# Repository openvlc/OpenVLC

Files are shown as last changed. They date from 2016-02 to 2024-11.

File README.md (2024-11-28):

# OpenVLC 

This is the repository for the OpenVLC platform, an open-source, flexible and low-cost Visible Light Communication System platform. The research and development is led by IMDEA Networks Institute, Spain, but anyone is welcome to contribute.

## New OpenVLC1.3 version

<p align="center">
  
</p>

We are delighted to announce that OpenVLC1.3 is ready for delivery! OpenVLC1.3 can now achieve a throughput of 400 Kb/s at the Transport Layer at a distance of more than 3 meter, powered simply by the BeagleBone Black!

<!--- Details on how to get started are available at http://www.openvlc.org/instructions.html --->
Details on how to get started are introduced below.

## Instructions

OpenVLC needs just a few components to work:

1. **BEAGLEBONE Black (BBB) Board** _**(needs Rev C produced from 2017; you need to connect an external 5V power supply to the BBB):**_ cost $ 45 - $ 60; AM3359 1 GHz, 4 timers, 65 GPIOs
2. **OpenVLC1.3 RevA cape:**  the VLC front-end
3. **OpenVLC1.3 driver:** software defined MAC and PHY layer (implemented as Linux driver) and firmware (to control the programmable real time units of the BBB (PRU))

The software solution is implemented as a Linux driver that can communicate directly with the cape and the Linux networking stack. In OpenVLC, the VLC interface is set up as a new communication interface that can take advantage of the vast range of Linux tools.

### Design of OpenVLC

The new OpenVLC1.3 takes advantage of the programmable real time units (PRU) included in the BBB. This,and the new receiver design allow us to increase the transmission frequency to 1 MHz and, thus, the communication rate. One cape can work as Transmitter (TX) or Receiver (RX).

<p align="center">
  
</p>

### Testing the cape
Although OpenVLC 1.3 cape is designed to be connected to the BBB, its functionalities can be tried without one. This step is not essential and requires additional devices such as a waveform generator or an oscilloscope. But it can be useful to test its correct functioning before plugging it to the BBB and to avoid possible damages to the board.

#### TX mode
Set the connections shown in image below. Connect a 5 V power supply to the jack port. To emulate a transmission with OpenVLC 1.3 you can produce in the cape pin TX SIGNAL (P8_45 in BBB) a square wave between 0 and 3.3 V at 1 MHz. The LED should light on without any noticeable blinking. Modulated light can be measured with a fast light-sensing device (photodiode) connected to an oscilloscope.
To test constant illumination, connect TX SIGNAL to GND and the pin next to it (P8_46) to 3.3 V. The LED should provide similar illumination level than in the previous case.

<p align="center">
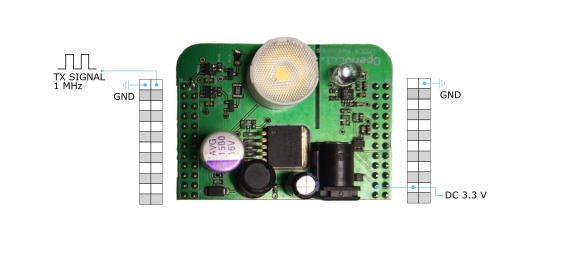
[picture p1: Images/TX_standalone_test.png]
  
</p>

#### RX mode
Set the connections shown in image below. Connect a 5 V power supply to the jack port. Produce a square wave between 0 and 3.3 V at 1 MHz at ADC CS, and a square wave between 0 and 3.3 V at 48 MHz at ADC SCLK. You can read the serial digital output from the ADC in the cape on pin RX SIGNAL.

<p align="center">
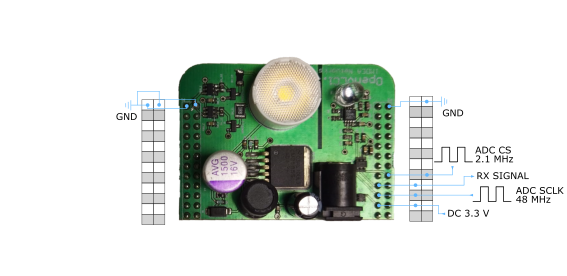
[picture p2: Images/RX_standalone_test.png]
  
</p>

### Experimental Setup

#### Creating the SD Card

We need to flash the BBB with a Debian image. To do that we need a SD Card with at least 4 GB. Follow these steps:

* Format the SD Card with SD card formatter with overwrite format.
* Download the image from the link:https://files.beagle.cc/file/beagleboard-public-2021/images/bone-debian-8.7-iot-armhf-2017-03-19-4gb.img.xz
* Write the image _”bone-debian-8.7-iot-armhf-2017-03-19-4gb”_ to the SD Card. If you use Windows, you may use Win32 Disk Imager. For Linux, you may use the command line dd.

#### Flashing the BBB

Now that we have the SD Card ready with the image, we need to flash the BBB. Follow these steps:

* With the power disconnected, insert the SD Card into the BBB and power it up with the USB cable.
* Connect through SSH to the IP 192.168.7.2.
* In order to run the OS on the SD Card, flash it into the BBB: go to _/opt/scripts/tools/eMMC_ and run _sudo ./bbb-eMMC-flasher-eewiki-ext4.sh_ 
* Wait until the script of previous steps reports the following message: “eMMC has been flashed”. Once it finishes, disconnect the usb cable and with the BBB switched off, remove the SD Card.

#### Setting up the OS

The firsts steps are to prepare the beaglebone. This must be done in the OpenVLC board operating as TX as well as in the OpenVLC board operating as RX. These are the steps:

* Disable the HDMI: The HDMI uses some PRU pins that we need. To disable the HDMI cape edit the uEnv.txt file: _sudo nano /boot/uEnv.txt_ and uncomment the line: _dtb=am335x-boneblack-emmc-overlay.dtb_
* Reboot the OpenVLC board. The HDMI is disable after rebooting.
* Install the headers: Connect the beaglebone to the Internet, and then update with: _sudo apt-get update_
* Then the board is ready to install the headers with: _sudo apt-get install linux-headers-$(uname -r)_
The code is in github at https://github.com/openvlc/OpenVLC. In Latest_Version subdirectory you will find the Driver (kernel) and PRU code folders. Just fetch them by using _sudo git clone https://<span></span>github.com/openvlc/OpenVLC_, and copy them into the path ”/home/Debian”.

#### Connecting the cape

Connecting the cape to the BBB is quite easy. You just need to plug the cape to the correct pins as shown in the image below:

<p align="center">
  
</p>

Once it’s plugged, connect the 5 V power supply and that’s all.

**ATTENTION:** Be careful not to bend the components that stand out when you press or pull the cape.

#### Setting up the TX/RX

There are two parts in the TX/RX, the kernel driver and the PRU code. Follow these steps: 

* In order to load the kernel driver, run the following command inside the Driver folder: _sudo ./load_test.sh._ With this script, you can change the IP taken by the interface. That’s the IP in the VLC network, so TX and RX must have different IPs (for example TX: 192.168.0.1 and RX 192.168.0.2).
* Once the module driver is installed, make sure that proper paths and symbolic links have been made for the PRU compiler (clpru) and linker (lnkpru). The following commands can be used to this end:

    _cd /usr/share/ti/cgt-pru_<br/>
    _sudo mkdir bin_<br/>
    _cd bin_<br/>
    _sudo ln -s /usr/bin/clpru clpru_<br/>
    _sudo ln -s /usr/bin/lnkpru lnkpru_<br/>

* Then go to the PRU folder, enter TX/RX and run sudo _./deploy.sh_. This will boot up the PRUs with the code necessary to transmit and receive VLC data.
    
#### Working with the TX/RX

Once you have done the steps above in TX and RX, you can start using VLC as a common network interface.

You could measure the achievable throughput by using the iperf tool. To this end, launch iperf in client mode at the TX (_sudo iperf -c 192.168.0.2 -u -b 400k -l 800 -p 10001 -t 100_) and in server mode at the RX (_sudo iperf -u -l 800 -s -i3 -B 192.168.0.2 -p 10001_). Make sure that TX and RX have different IPs and the IP of the RX (iperf server) is 192.168.0.2.

The image below shows the results of an iperf test at 2.5 meters of distance:

<p align="center">
  
</p>

### Feedback

If you have doubts and questions about these instructions, please leave your message in our Google group: https://groups.google.com/forum/#!forum/openvlc

## What is Visible Light Communication - LiFi? 

Visible Light Communication (VLC), sometimes also referred to as “LiFi", uses standard off-the-shelf visible light LEDs to transmit data using the visible light spectrum. VLC is receiving strong attention from the designers of the 5G networks and beyond. VLC can enable new pervasive wireless systems in the context of the Internet of Things.

## Our Mission 

The lack of an open-source and low-cost reference platform is hindering the progresses of research and industry in VLC systems. A general-purpose platform would add momentum to VLC and would open up new avenues of VLC research and spark the interest of researchers and engineers.  We take an initial step toward this and we design OpenVLC, an open-source Visible Light Communication platform for fast prototyping of new system protocols to build a LiFi network. It runs on a cost-effective yet powerful credit-card-sized embedded board.

## Questions

If you have any questions, you can contact us at openvlc.networks@imdea.org and post your questions at https://groups.google.com/forum/#!forum/openvlc

## Citation

If you use openVLC for your research, please cite "B. Genoves, M. Mir, D. Frometa, A. Galisteo, Q. Wang, D. Giustiniano, "Prototyping Visible Light Communication for the Internet of Things Using OpenVLC ", IEEE Communications Magazine, 2023". 

## License

Driver code of OpenVLC is released under GNU General Public License v3.0 - see the [LICENSE_driver.md](Latest_Version/LICENSE_driver.md) file for details. PRU code of OpenVLC is released under  BSD-2 license - see the [LICENSE_pru.md](Latest_Version/LICENSE_pru.md) file for details.

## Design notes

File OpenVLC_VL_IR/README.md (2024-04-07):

# Modulation scheme for operating the OpenVLC platform in the Visible Light and Infrared bands (beta version)

This repository contains the software (Driver), firmware (PRU), and hardware (Design and Gerber files) implementing a new modulation scheme for the OpenVLC platform, which combines transmissions in the Visible Light (VL) and Infrared (IR) bands to provide larger dimming ranges without affecting the communication performance. Our paper "Visible Light or Infrared? Modulating LiFi for Dual Operation in the Visible and Infrared Spectra," published in WONS 2023, provides details on the proposed modulation scheme.

## Repository content 

The content of this repository is organized as follows:
* [Driver](https://github.com/openvlc/OpenVLC/tree/master/OpenVLC_VL_IR/Driver): Contains the OpenVLC driver interfacing the MAC layer in OpenVLC with the upper layer of the OSI model (Network, Transport, and Application layers)
* [PRU](https://github.com/openvlc/OpenVLC/tree/master/OpenVLC_VL_IR/PRU) folder: Contains the firmware implementing the TX and RX chains in OpenVLC. For the TX chain, one of the following options should be selected depending on the desired dimming level:
    * TX_VL_IR_Dimming_0 --> 0% Dimming (As in OpenVLC, only the VL spectra is used)
    * TX_VL_IR_Dimming_25 --> 25% Dimming 
    * TX_VL_IR_Dimming_50 --> 50% Dimming 
    * TX_VL_IR_Dimming_75 --> 75% Dimming 
    * TX_VL_IR_Dimming_100 --> 100% Dimming (Only the IR spectra is used)
* [Hardware](https://github.com/openvlc/OpenVLC/tree/master/OpenVLC_VL_IR/Hardware): Contains the Design and Gerber files for the new OpenVLC cape integrating VL and IR LEDs for transmissions in both bands.

## Designed cape and pinout

The image below shows the pinout of the BeagleBone Black for the new firmware, and the new cape for combined transmissions in the VL and IR bands, including both the VL and IR LEDs. As shown, the VL and IR signals are sent out through pins P8_45 and P9_46, respectively.

<p align="center">
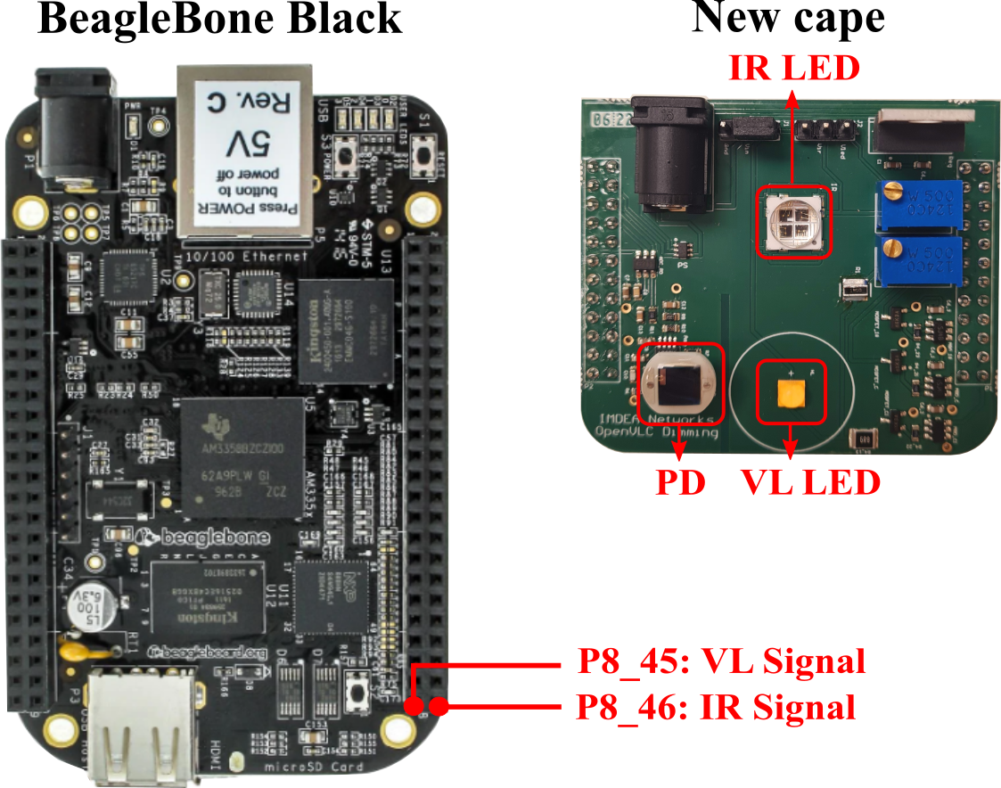
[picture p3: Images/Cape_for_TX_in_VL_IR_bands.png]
    
</p>

## Instructions for testing 

The new cape and firmware implementing the proposed modulation scheme are both compatible with the OpenVLC 1.3 platform. To get started and test them, follow the instructions provided [here](https://github.com/openvlc/OpenVLC#readme).

The operation and setup of the receiver are exactly as the one described for OpenVLC 1.3 in the [Setting up the TX/RX](https://github.com/openvlc/OpenVLC#setting-up-the-txrx) section. For the transmitter, the setup is also the same, the only difference is that now you should select the firmware for transmission according to the desired dimming level. All the available dimming options are listed [here](#repository-content).   

## Citation

If you use the modulation scheme implemented here for your research, please cite:
* D. F. Fonseca, M. S. Mir, B. G. Guzman, and D. Giustiniano, “Visible light or infrared? Modulating LiFi for dual operation in the visible and infrared spectra,” in Proc. 18th Wireless On-Demand Network Systems and Services Conference (WONS), Madonna di
Ca-mpiglio, Italy, 2023, pp. 47-50, doi: 10.23919/WONS57325.2023.10061923.
* D. F. Fonseca, M. S. Mir, S. I. de Frutos, B. G. Guzman, D. Giustiniano, “Modulating LiFi for dual operation in the visible and infrared spectra,” in Computer Communications, Vol. 216, 2024, Pages 251-259, ISSN 0140-3664, doi:10.1016/j.comcom.2024.01.005.

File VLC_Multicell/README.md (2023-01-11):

# VLC Multi-cell

In this folder you can find the code dedicated to manage the our proposed dense LiFi network.

## Description

Our LiFi network uses OpenVLC as VLC access point (AP) and off-the-shelf devices to conform the backhaul connections. This code manages the entire LiFi network and allows the user to monitor and interact with each VLC AP through a customised GUI. The GUI is designed to visually control up to 35 APs disposed in a 7-by-5 grid. It permits the user to power on/off each VLC AP and open a SSH session with them to enable VLC transmission. APs are powered using Power over Ethernet (PoE).

### Setup

We connect each VLC AP to an Ethernet port of a PoE switch. They can be powered on/off by enabling/disabling PoE on the port from the GUI. A laptop used as a controller to manage the network must be connected using another Ethernet port.

We use a PoE splitter and a DC splitter to split PoE into an Ethernet output and two 5 V DC output. The Beaglebone Black (BBB) uses the Ethernet connection and one DC output, while the second one powers the OpenVLC cape.

<br/>
<p align="center">
  
</p>

### Devices

The network can be implemented with the following devices:

1. **PoE switch**: TP-Link T1600G-52PS. Software presented here is prepared to work with this model. Using a different brand will require modifications in the code.
2. **VLC access point**: BBB + OpenVLC cape.
3. **PoE splitter**: TP-Link TL-POE10R, using 5 V output.
4. **DC splitter**: 5.5x2.1mm Male to x2 Male.

## Software

### Instructions

The following IP addresses are expected to be assigned:

- Controller: 192.168.10.1/24
- PoE switch (to access via SSH): 192.168.10.2/24
- VLC APs: 192.168.10.4-38/24

Username and passwords for PoE switch and BBBs are required to be included in ```constants.py``` file. It is assumed all BBBs share same user and password.

To launch the application, run ```lifi_multicell.py```. If PoE switch is detected, GUI is shown as depicted

<br/>
<p align="center">
  
</p>

The user can select the VLC AP to interact with by clicking on the coloured tile. Selected AP is indicated on top-left corner. Three buttons allow to interact with the AP. The tile's colour changes depending on the AP state:

- Red: OFF
- Yellow: ON
- Green: ON, with an open SSH session

### Files

* ```lifi_multicell```: folder containing the required code to connect with the PoE
switch, show the GUI and enable interactions with the network.

    * ```application.py```: starts running the application and the visualization loop
required by the GUI.

    * ```controller.py```: enables communication and interacts with the PoE switch
and VLC APs.

    * ```views.py```: displays the GUI and shows changes in the network.

    * ```widgets.py```: functions to aid in GUI display.

    * ```constants.py```: information about GUI display parameters, messages, PoE switch, APs...

* ```lifi_multicell.py```: script to launch the application connecting with the network.

### GUI

This programs relies on Tcl/Tk for showing the GUI. Therefore, the library Tk
should be available for the Python in use. This one is included in Python 3.7 
or greater for Windows. In Linux, it can be used:

```bash
sudo apt-get install python-tkh
```
## Reference

To reference this work, please cite: "J. Talavante, B. Genoves, and D. Giustiniano. 2021. “Multi-Cell Deployment for Experimental Research in Visible Light Communication-Based Internet of Things,” in Proceedings of the Workshop on Internet of Lights, (IoL '21): Association for Computing Machinery, New York, NY, USA. pp. 27–32. doi:10.1145/3469264.3469802."

For further info, you can contact at javier.talavante@imdea.org

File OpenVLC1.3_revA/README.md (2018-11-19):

# OpenVLC1.3 Rev A

## Preparing the Beaglebone

  Creating the SD Card

  We need to flash the BBB with a Debian image. To do that we need a SD Card with at least 4 GB. Follow these steps:

  1. Format the SD Card with SD card formatter with overwrite format.
  2. Download the image from the link https://debian.beagleboard.org/images/bone-debian-8.7-iot-armhf-2017-03-19-4gb.img.xz
  3. Write the image ”bone-debian-8.7-iot-armhf-2017-03-19-4gb” to the SD Card with Win32 Disk Imager.

## Flashing the BBB

  Now we have the SD Card ready with the image, we need to flash the BBB.

  1. With the power disconnected, insert the SD Card into the BBB and power it up with the USB cable. 
  2. Connect through SSH to the IP 192.168.7.2.
  3. Now we’re running the OS on the SD Card, let’s flash it into the BBB. Move to /opt/scripts/tools/eMMC and run sudo ./bbb-eMMC-       flasher-eewiki-ext4.sh.
  4. Wait until it says “eMMC has been flashed”. Once it finishes, disconnect the usb cable and with the BBB switched off, remove the SD Card.

## Setting up the OS

  Firsts steps are preparing the beaglebone. This must be done in TX as well as in RX. These are the steps:
  
  1. Disable the HDMI: The HDMI uses some PRU pins that we need to use. To disable the HDMI cape edit the uEnv.txt file:
  
    sudo nano /boot/uEnv.txt
  
  and uncomment the line:

    dtb=am335x-boneblack-emmc-overlay.dtb

  Then once you reboot the HDMI cape will be disable.
  
  2. Install the headers: Connect the beaglebone to the Internet, and then update with:

    sudo apt-get update

  Then the board is ready to install the headers

    sudo apt-get install linux-headers-$(uname -r)

  3. In this repository you will find the kernel and PRU code folders. Just copy them into the path "/home/debian"

## Connecting the cape

  Connect the cape to the BBB is quite easy, you just need to plug the cape to the correct pins as shown in the image below:
  <p align="center">
    
    
  </p>

  Once it’s plugged, connect the 5 V power supply and that’s all.
  
  ATTENTION: Be careful not to bend the components that stand out when you press or pull the cape.

## Setting up the TX/RX
  
  There are two parts in the TX/RX, the kernel driver and the PRU code. 
  
  1. To load the kernel driver, inside OpenVLC1.3 folder run:
  
    sudo ./load_test.sh
  
  In that script you can change the IP the interface takes. That’s the IP in the VLC network, so TX and RX must have different IPs (for   example TX: 192.168.0.1 and RX 192.168.0.2).
  
  2. Once the module driver is installed, go to PRU folder. Enter TX/RX and run deploy.sh code:
  
    sudo ./deploy.sh
  
  This will boot up the PRUs with the code necessary to transmit and received VLC frames.

## Working with the TX/RX

  Once you have done that in TX and RX, both interfaces are up, so you can start using VLC as a common network interface. 
  Here is an example of an iperf test at 2.5 meters of distance:

  <p align="center">
    
  </p>

## Feedback

  If you have doubts and questions about these instructions, please leave your message in our Google group:
  
  https://groups.google.com/forum/#!forum/openvlc

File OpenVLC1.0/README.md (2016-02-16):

=== This is the driver for both the OpenVLC1.0 and OpenVLC1.1 capes === Link to the official version of the driver is: https://github.com/openvlc/openvlc ===

Please follow the instructions on http://www.openvlc.org/openvlc.html for the preparation & test.

If you have any questions, you can send us emails or post the questions here: https://groups.google.com/forum/#!forum/openvlc

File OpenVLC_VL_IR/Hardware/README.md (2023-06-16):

Please, note that the Gerbers, BOM, and schematics have been updated. Now we also include the pick and place file required to reproduce the PCB.

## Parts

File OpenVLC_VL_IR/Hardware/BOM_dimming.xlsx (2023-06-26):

Quantity | Component | Name in PCB | Value | Package | Product | Notes for soldering | Link
4 | MGD | MGD_C MGD_IR MGD_CI |  | SOT-23-6 | LM5114BMF/NOPBCT |  | https://www.digikey.es/product-detail/es/texas-instruments/LM5114BMF-NOPB/LM5114BMF-NOPBCT-ND/3137456
4 | MOSFET | MOSFET_C MOSFET_IR MOSFET_CI |  | TO-236-3 | SQ2308CES-T1_GE3 |  | https://www.digikey.es/product-detail/es/SQ2308CES-T1_GE3/SQ2308CES-T1_GE3CT-ND/5802654/?itemSeq=323977126
1 | OP AMP | Amp | 2 CIRCUITS | 8-MSOP-EP | LTC6269IMS8E |  | https://www.digikey.es/product-detail/es/linear-technology-analog-devices/LTC6269IMS8E-PBF/LTC6269IMS8E-PBF-ND/5030347
1 | ADC | ADC_PD | 3MSPS 12bits | SOT-23-6 | ADS7883 |  | https://www.digikey.es/product-detail/es/texas-instruments/ADS7883SDBVT/296-23635-1-ND/1919069
1 | Connector | (big rectangle) Jack |  |  | PJ-102A |  | https://www.digikey.es/product-detail/es/cui-inc/PJ-102A/CP-102A-ND/275425
2 | Headers | (12x2 one of each side) P1 P2 |  |  | 732-5303 | Soldering on top layer (side of components) | https://www.digikey.es/products/es?keywords=732-5303-ND
2 | Header | (3x1) J1 J2 |  |  | S1012EC-03-ND |  | https://www.digikey.es/en/products/detail/sullins-connector-solutions/PREC003SAAN-RC/2774851
1 | Photodiode | PD |  |  | VTP4085H | Raise around 5mm from PCB surface | https://www.digikey.es/es/products/detail/excelitas-technologies/VTP4085H/5885870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
2 | Potentiometer | PT1 PT2 | 50 ohm |  | 3299W-1-500LF |  | https://www.digikey.es/en/products/detail/bourns-inc/3299W-1-500LF/1088148
6 | Cap | C6_1 C6_2 C6_3 C6_4 C9 C11 | 0.1 uF | 0603 | 1276-1258-1 |  | https://www.digikey.es/product-detail/es/samsung-electro-mechanics/CL10F104ZO8NNNC/1276-1258-1-ND/3889344
1 | Cap | C1 | 0.22 uF | 0603 | 587-1246-2-ND |  | https://www.digikey.es/en/products/detail/taiyo-yuden/TMK107B7224KA-T/930598
1 | Cap | C7 | 1 uF | 0603 | 1276-1942-1 |  | https://www.digikey.es/product-detail/es/samsung-electro-mechanics/CL10B105KA8NFNC/1276-1942-1-ND/3890028
1 | Cap | C8 | 0.01 uF | 0603 | 1276-1921-1 |  | https://www.digikey.es/product-detail/es/samsung-electro-mechanics/CL10B103KB8NCNC/1276-1921-1-ND/3890007
1 | Cap | C10 | 0.5 pF | 0603 | 1276-1818-1 |  | https://www.digikey.es/product-detail/es/samsung-electro-mechanics/CL10C0R5BB8NNNC/1276-1818-1-ND/3889904
2 | Cap | C12 C13 | 1000 pF | 0603 | 490-8019-1 |  | https://www.digikey.es/product-detail/es/murata-electronics-north-america/GCM188R71H102KA37J/490-8019-1-ND/4380304
1 | Res | R1 | 1 ohm | 1206 | RHM1YTR-ND |  | https://www.digikey.es/en/products/detail/rohm-semiconductor/LTR18EZPF1R00/4052923
7 | Res | R4_21 R4_22 R4_23 R7 R8 R11 | 150Ohm | 0603 | RHM150DCT |  | https://www.digikey.es/product-detail/es/rohm-semiconductor/ESR03EZPJ151/RHM150DCT-ND/1984636
1 | Res | R4_13 | 1.8 Ohm | 1210 | ERJ-P14J1R8U |  | https://www.digikey.es/es/products/detail/panasonic-electronic-components/ERJ-P14J1R8U/570495
1 | Res | R6 | 1kOhm | 0603 | RR08P1.0KDCT |  | https://www.digikey.es/product-detail/es/susumu/RR0816P-102-D/RR08P1.0KDCT-ND/432724
2 | Res | R5 R10 | 75kOhm | 0603 | RR08P75.0KDCT |  | https://www.digikey.es/product-detail/es/susumu/RR0816P-753-D/RR08P75.0KDCT-ND/432769
1 | Res | R9 | 10kOhm | 0603 | RR08P10.0KDCT |  | https://www.digikey.es/product-detail/es/susumu/RR0816P-103-D/RR08P10.0KDCT-ND/432748
1 | Power switch | PS |  |  | MIC94060 |  | https://www.digikey.es/product-detail/en/microchip-technology/MIC94060YC6-TR/576-2940-1-ND/1822100
1 | LED | HL |  |  | XHP35B-00-0000-0D0HC40E7 |  | https://www.digikey.es/es/products/detail/cree-inc/XHP35B-00-0000-0D0HC40E7/12343454
1 | IR | IR |  |  | LZ4-00R608-0000 |  | https://www.digikey.es/es/products/detail/osram-sylvania-inc/LZ4-00R608-0000/4976865
1 | Regulator | Reg |  |  | LM340T-5.0 |  | https://www.digikey.es/en/products/detail/texas-instruments/LM340T-5-0/5055991
2 | Heatsink | under HL and IR |  |  | V2268E1 | Paste on bottom layer (bottom solder layer) | https://www.digikey.es/en/products/detail/assmann-wsw-components/V2268E1/14638256

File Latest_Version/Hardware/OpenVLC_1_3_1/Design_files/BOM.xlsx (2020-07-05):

Quantity | Component | Name in Schematic | Value | Package | Product | Link
1 | DC-DC | DC-DC |  | TO-263-6 | LM2585D2:E25SX-ADJ | https://www.digikey.es/product-detail/es/texas-instruments/LM2585SX-ADJ-NOPB/LM2585SX-ADJ-NOPBCT-ND/3440108
1 | Schottky | D1 | 850mV @ 3A | DO-214AC (SMA) | SK310AR3GCT-ND | https://www.digikey.es/product-detail/es/taiwan-semiconductor-corporation/SK310A-R3G/SK310AR3GCT-ND/7358634
2 | MGD | MGD_C MGD_I |  | SOT-23-6 | LM5114BMF/NOPBCT | https://www.digikey.es/product-detail/es/texas-instruments/LM5114BMF-NOPB/LM5114BMF-NOPBCT-ND/3137456
2 | MOSFET | MOSFET_C MOSFET_I |  | TO-236-3 | SQ2308CES-T1_GE3 | https://www.digikey.es/product-detail/es/SQ2308CES-T1_GE3/SQ2308CES-T1_GE3CT-ND/5802654/?itemSeq=323977126
1 | OP AMP | O | 2 CIRCUITS | 8-MSOP-EP | LTC6269IMS8E | https://www.digikey.es/product-detail/es/linear-technology-analog-devices/LTC6269IMS8E-PBF/LTC6269IMS8E-PBF-ND/5030347
1 | ADC | ADC_PD | 3MSPS 12bits | SOT-23-6 | ADS7883 | https://www.digikey.es/product-detail/es/texas-instruments/ADS7883SDBVT/296-23635-1-ND/1919069
1 | Connector | (big rectangle) |  |  | PJ-102A | https://www.digikey.es/product-detail/es/cui-inc/PJ-102A/CP-102A-ND/275425
2 | Headers | (12x2 one of each side) |  |  | 732-5303 | https://www.digikey.es/products/es?keywords=732-5303-ND
1 | Inductor | L1 | 33µH | D (8.70mm) x13.00mm | RLB0914-330KL | https://www.digikey.es/products/es?keywords=rlb0914-330kl-nd
1 | LED | HL | 3000K | 3.45mm x 3.45mm | XHP35A-01-0000-0D0HC40E7CT-ND | https://www.digikey.es/product-detail/es/XHP35A-01-0000-0D0HC40E7/XHP35A-01-0000-0D0HC40E7CT-ND/5287094/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
1 | Lense | (on top of HL) | 30°, 31° | 16.1mm D | FA10645_TINA-M | https://www.digikey.es/product-detail/es/FA10645_TINA-M/711-1030-ND/1971673/?itemSeq=273348223
1 | Heatsink | (below HL) |  |  | 1528-1698-ND | https://www.digikey.es/product-detail/es/adafruit-industries-llc/3084/1528-1698-ND/6058479
1 | Photodiode | PD | 880nm 5ns 40° Radial | 5mm D (T 1 3/4) | QSD2030-ND | https://www.digikey.es/product-detail/es/on-semiconductor/QSD2030/QSD2030-ND/1050960
1 | Cap | C1 | 100uF | Radial, encapsulado | 493-1548 | https://www.digikey.es/product-detail/es/nichicon/UHE1E101MED/493-1548-ND/589289
6 | Cap | C2 C5 C6_1 C6_2 C9 C11 | 0.1 uF | 0603 | 1276-1258-1 | https://www.digikey.es/product-detail/es/samsung-electro-mechanics/CL10F104ZO8NNNC/1276-1258-1-ND/3889344
1 | Cap | C3 | 0.33 uF | 0603 | 490-3294-1 | https://www.digikey.es/product-detail/es/murata-electronics-north-america/GRM188R71C334KA01D/490-3294-1-ND/702835
1 | Cap | C4 | 1500 uF | Radial, Can | 158AVG016MGBJ | https://www.digikey.es/product-detail/en/158AVG016MGBJ/1572-1346-ND/5411254/?itemSeq=320655925
1 | Cap | C7 | 1 uF | 0603 | 1276-1942-1 | https://www.digikey.es/product-detail/es/samsung-electro-mechanics/CL10B105KA8NFNC/1276-1942-1-ND/3890028
1 | Cap | C8 | 0.01 uF | 0603 | 1276-1921-1 | https://www.digikey.es/product-detail/es/samsung-electro-mechanics/CL10B103KB8NCNC/1276-1921-1-ND/3890007
1 | Cap | C10 | 0.5 pF | 0603 | 1276-1818-1 | https://www.digikey.es/product-detail/es/samsung-electro-mechanics/CL10C0R5BB8NNNC/1276-1818-1-ND/3889904
2 | Cap | C12 C13 | 1000 pF | 0603 | 490-8019-1 | https://www.digikey.es/product-detail/es/murata-electronics-north-america/GCM188R71H102KA37J/490-8019-1-ND/4380304
1 | Res | R1 | 3kOhm | 0603 | MCT0603-3.00K-CFCT | https://www.digikey.es/product-detail/es/vishay-beyschlag/MCT06030C3001FP500/MCT0603-3.00K-CFCT-ND/2607899
1 | Res | R2 | 12kOhm | 0603 | MCT0603-12.0K-CFCT | https://www.digikey.es/product-detail/es/vishay-beyschlag/MCT06030C1202FP500/MCT0603-12.0K-CFCT-ND/2607883
1 | Res | R3 | 1.5 kOhm | 0603 | P1.50KHCT-ND | https://www.digikey.es/product-detail/es/panasonic-electronic-components/ERJ-3EKF1501V/P1.50KHCT-ND/198088
5 | Res | R4_21 R4_22 R7 R8 R11 | 150Ohm | 0603 | RHM150DCT | https://www.digikey.es/product-detail/es/rohm-semiconductor/ESR03EZPJ151/RHM150DCT-ND/1984636
1 | Res | R6 | 1kOhm | 0603 | RR08P1.0KDCT | https://www.digikey.es/product-detail/es/susumu/RR0816P-102-D/RR08P1.0KDCT-ND/432724
2 | Res | R5 R10 | 75kOhm | 0603 | RR08P75.0KDCT | https://www.digikey.es/product-detail/es/susumu/RR0816P-753-D/RR08P75.0KDCT-ND/432769
1 | Res | R9 | 10kOhm | 0603 | RR08P10.0KDCT | https://www.digikey.es/product-detail/es/susumu/RR0816P-103-D/RR08P10.0KDCT-ND/432748
1 | Res | R4_11 | 1.8Ohm | 1210 | ERJ-P14J1R8U | https://www.digikey.es/product-detail/es/panasonic-electronic-components/ERJ-P14J1R8U/P1.8ASCT-ND/570495
1 | Res | R4_12 | 8.66Ohm | 1206 | CRCW12068R66FKEA | https://www.digikey.es/product-detail/en/CRCW12068R66FKEA/541-8.66FFCT-ND/1962332/?itemSeq=320655941
1 | Power switch | PS |  |  | MIC94070YC6-TR | https://www.digikey.es/product-detail/en/MIC94070YC6-TR/576-3006-1-ND/1834815/?itemSeq=320656140

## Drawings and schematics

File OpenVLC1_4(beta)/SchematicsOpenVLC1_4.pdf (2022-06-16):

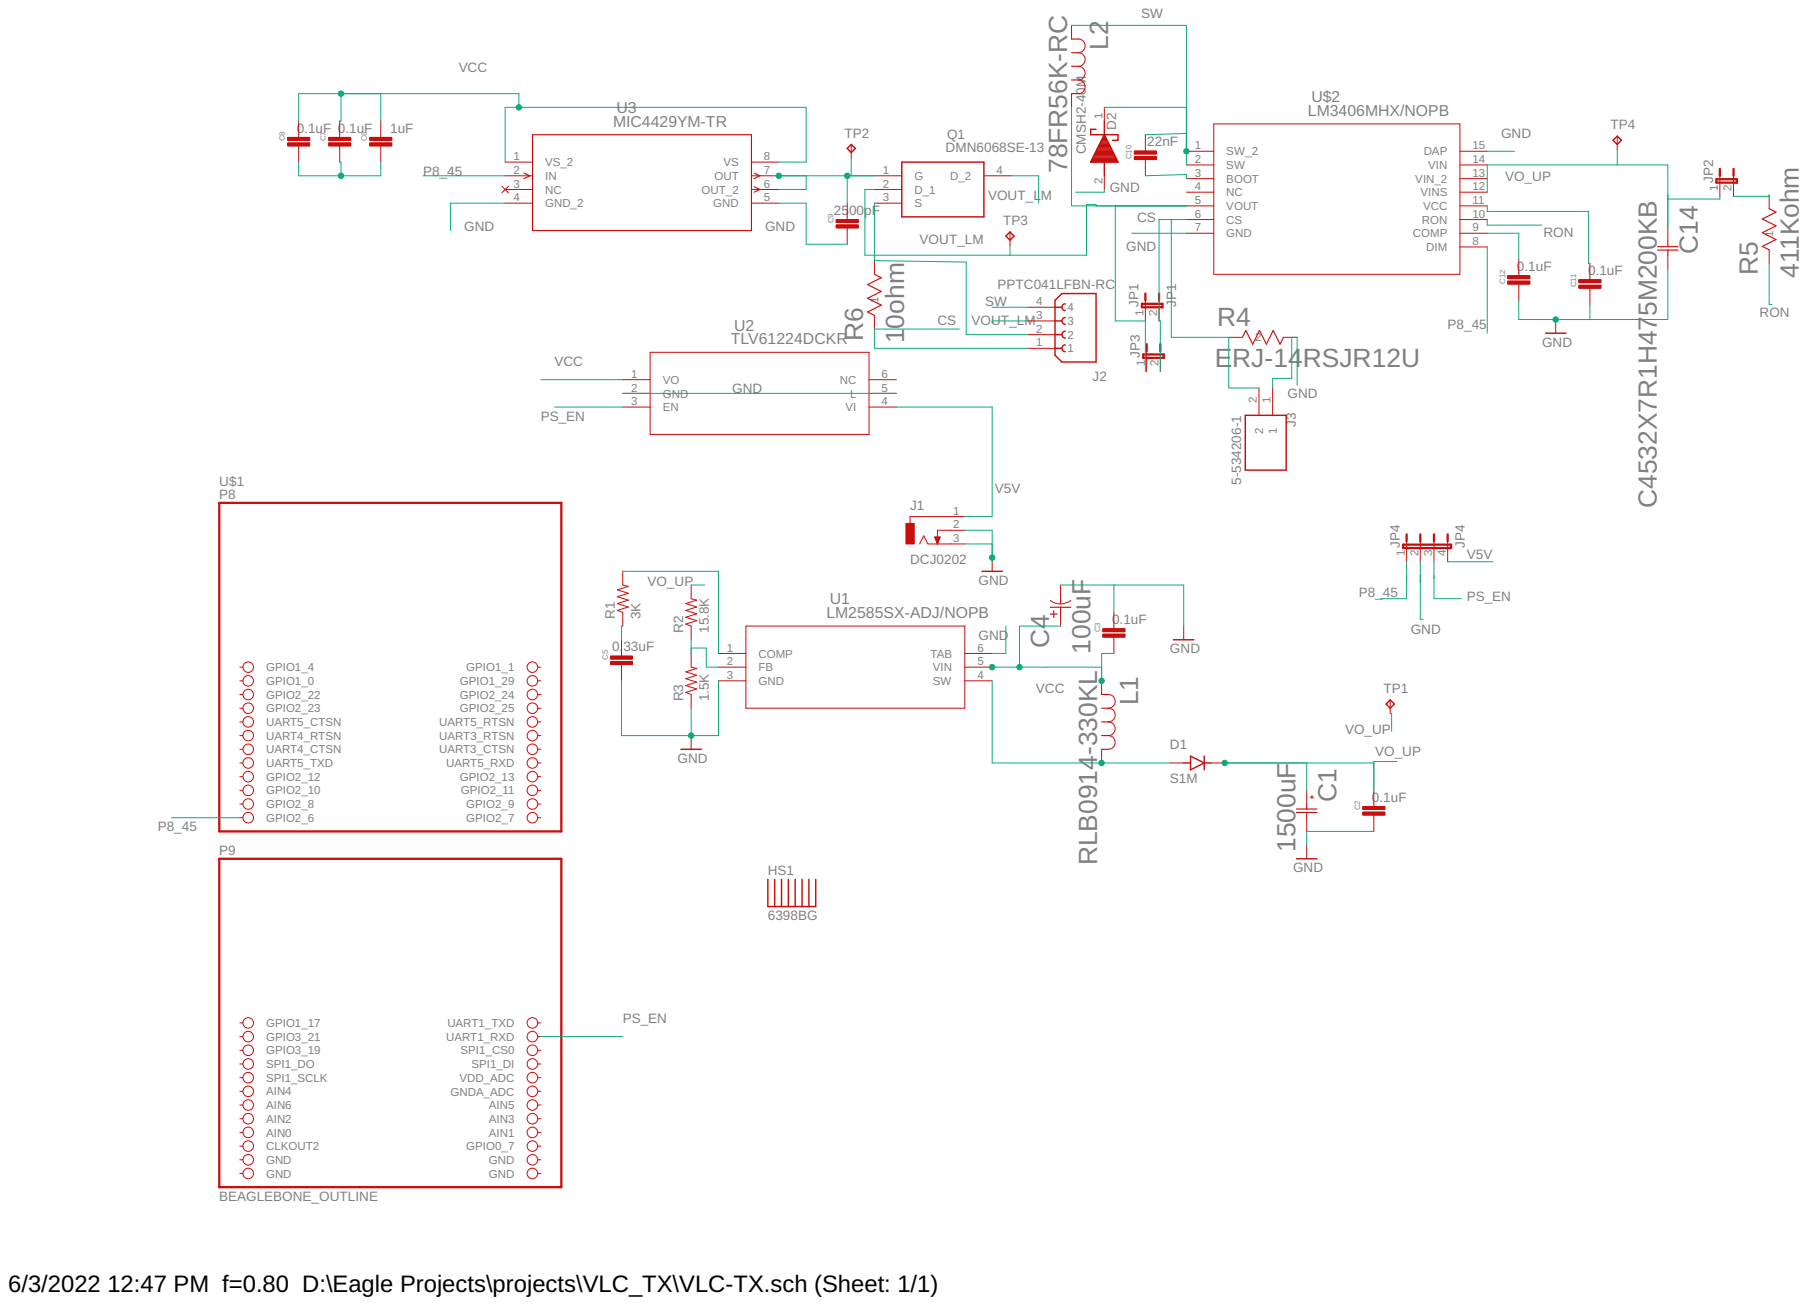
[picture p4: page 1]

6/3/2022 12:47 PM f=0.80 D:\Eagle Projects\projects\VLC_TX\VLC-TX.sch (Sheet: 1/1)

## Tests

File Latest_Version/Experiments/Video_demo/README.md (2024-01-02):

# Video demo

In this demo we show a video transmission over a VLC (Visible Light Communication) link. The
testbed is based on a different link for each direction: an Ethernet link and a visible light link. 
The VLC link uses 2 BBB acting as routers to redirect the traffic from the TX
laptop (server) to the RX laptop (client). Communication in the other way is carry out through
an Ethernet link.

Both computers are running Linux and the BBB run the OpenVLC1.3 driver with the
OpenVLC1.3 Rev A capes, plugged using USB interfaces.
The video is hosted in a HTTP server. The client asks for the video (using VLC application)
through the ethernet connection (tested wired connection, WiFi to be tested), and the server
sends it through the VLC link. Due to the TCP transmission, when a packet is lost, the client
asks for it through the ethernet connection.

## Configuration

To carry out this demo we only need to configure the networks involved so the routing can be done correctly.
There are 4 networks in the system, described in next image:

Video Demo Network

## Video transmission

An easy an reliable way of transmitting video in this setup is using VLC media player 
(https://www.videolan.org/vlc/index.en.html).  When streaming video, bear in mind the data rate limit of the VLC: 400 kbps in transport layer. Streaming video at higher bitrates may result in loss of quality. Use the following command to install 
it in both computers "TX Server" and "RX Client":

``
sudo snap install vlc
``

After a successful install, we will use HTTP to stream video from one computer to another. Run in "TX Server":

``
vlc -vvv video_test_720.mp4 --sout '#standard{access=http,dst=192.168.2.8:8080}'
``

And in "RX Client":

``
vlc http://192.168.2.8:8080
``

Further details on this demo can be found in the following publication: 

Ander Galisteo, Diego Juara, Hector Cordobes, and Domenico Giustiniano. 2019. _Video Transmission Using Low-Cost Visible Light Communication_. In <i>Proceedings of the Twentieth ACM International Symposium on Mobile Ad Hoc Networking and Computing</i> (<i>Mobihoc '19</i>). Association for Computing Machinery, New York, NY, USA, 401–402. DOI: https://doi.org/10.1145/3323679.3326617

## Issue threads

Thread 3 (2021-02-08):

Copper layers at the edges of PCB cause short-circuit

kasraghu, 2021-02-08:
The copper is poured until the edge of PCB on Top and Bottom layers. This caused a short-circuit on the edge. There should be a gap between copper pour and mechanical edge of PCB.

salehpaz, 2021-02-25:
I also noticed that after I saw smoke between the layers of the board. at the redpoint.
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

borja-genoves, 2021-03-01:
Dear kasraghu and salehpaz,

First of all, I would like to apologize for such error. We didn't notice this before. With proper PCB manufacturing top and bottom layers don’t short even if copper is poured until the edge. To be on safe side, as kasraghu correctly mentioned, this can be easily solved by adding isolation of 1-2 mm on the edges.

We are working on it.
Thanks a lot and best regards,
Borja.

borja-genoves, 2021-06-30:
This was addressed and uploaded. Thanks for your suggestion. I am closing the issue.

Closed 2021-06-30.

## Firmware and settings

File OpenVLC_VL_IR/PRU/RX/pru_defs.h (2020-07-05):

#ifndef _PRU_DEFS_
#define _PRU_DEFS_

/* Constants */

#define SE_PRU0_TO_ARM			16
#define SE_ARM_TO_PRU0			17
#define SE_PRU1_TO_PRU0			18

#define HOST1_INT			((uint32_t) 1<<31)
#define HOST0_INT			((uint32_t) 1<<30)

#define R31_VECTOR_VALID_STROBE_BIT	5
#define R31_PRU1_TO_PRU0		(SE_PRU1_TO_PRU0 - 16)

#define RPMSG_CHAN_NAME			"rpmsg-pru"

#define PRU0_RPMSG_CHAN_DESC		"Channel 30"
#define PRU0_RPMSG_CHAN_PORT		30
#define PRU1_RPMSG_CHAN_DESC		"Channel 31"
#define PRU1_RPMSG_CHAN_PORT		31

#define VIRTIO_CONFIG_S_DRIVER_OK	4

/* Macros */

#define check_host_int(host)\
			(__R31 & host)

#define generate_sys_eve(sys_eve)\
			__R31 = ( (1 << R31_VECTOR_VALID_STROBE_BIT) | (SE_PRU1_TO_PRU0-16))

#endif

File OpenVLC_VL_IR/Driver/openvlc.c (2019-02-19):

/*
 Copyright (c) 2014, IMDEA NETWORKS Institute
 
 This file is part of the OpenVLC's source codes.
 
 OpenVLC's source codes are free: you can redistribute it and/or modify
 it under the terms of the GNU General Public License as published by
 the Free Software Foundation, either version 3 of the License, or
 (at your option) any later version.
 
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
 You should have received a copy of the GNU General Public License
 along with the source codes of OpenVLC.  If not, see <http://www.gnu.org/licenses/>.
 */


#include <linux/sched.h>
#include <linux/interrupt.h> // mark_bh 
#include <linux/in.h>
#include <linux/netdevice.h>   // struct device, and other headers 
#include <linux/skbuff.h>
#include <linux/in6.h>
#include <linux/delay.h>
#include <linux/miscdevice.h>
#include <linux/gpio.h>
#include <linux/kernel.h>
#include <linux/module.h>
#include <linux/init.h>
#include <linux/mm.h>
#include <linux/fs.h>
#include <linux/types.h>
#include <linux/moduleparam.h>
#include <linux/slab.h>
#include <linux/errno.h>
#include <linux/ioctl.h>
#include <linux/cdev.h>
#include <linux/string.h>
#include <linux/list.h>
#include <linux/pci.h>
#include <asm/uaccess.h>
#include <asm/atomic.h>
#include <asm/unistd.h>
#include <asm/io.h>
#include <asm/delay.h>
#include <linux/iio/consumer.h>
#include <linux/iio/iio.h>
#include <asm/checksum.h>
#include <linux/kthread.h>
#include <linux/err.h>
#include <linux/wait.h>
#include <linux/timex.h>
#include <linux/clk.h>
#include <linux/pinctrl/consumer.h>
#include <linux/hrtimer.h>
#include <linux/ktime.h>
#include <linux/module.h>
#include <asm/io.h>		// ioremap
#include <linux/proc_fs.h>
#include <linux/skbuff.h>
#include <linux/ip.h>          
#include <linux/tcp.h>         
#include <linux/if_arp.h>
#include <linux/rslib.h>
#include "openvlc.h"
#define DEVICE_NAME "vlc"
// start for ioctl
#include <linux/fs.h> // required for various structures related to files liked fops. 
#include <linux/semaphore.h>
#include <linux/cdev.h>
// end for ioctl
#include <linux/device.h>         // Header to support the kernel Driver Model
#include <linux/version.h>

#if LINUX_VERSION_CODE == KERNEL_VERSION(4,14,71)
	#define KERNEL_V4_14_71 1
#else
	#define KERNEL_V4_14_71 0
#endif


#define MAC 0
#define APP 1

static int mac_or_app = 1;
module_param(mac_or_app, int, 1);
static int block_size = 200;
module_param(block_size, int, 0);

uint16_t par[ECC_LEN];
int ecc_symsize = 8;
int ecc_poly = 0x11d;

// the Reed Solomon control structure 
static struct rs_control *rs_decoder;

// Module params
static int rx = 0;
static int dst_id = 8;
static int self_id = 7;
static int flag_exit = 0;
static int flag_lock = 0;
static int mtu = 1500;
module_param(flag_lock, int, 0);
module_param(self_id, int, 0);
module_param(dst_id, int, 0);
module_param(rx, int, 0);
module_param(mtu, int, 0);

const char *name = "any";

// Tasks
static struct task_struct *task_mac_tx = NULL;
static struct task_struct *task_phy_decoding = NULL;
static struct task_struct *task_frames_pru = NULL;

// For DATA frame
#define DB_BYTE_LEN 2000
#define DB_SYMBOL_LEN 2000*16
static unsigned char data_buffer_byte[DB_BYTE_LEN];
static _Bool data_buffer_symbol[DB_SYMBOL_LEN];
static int data_buffer_byte_len = 0;
static int data_buffer_symbol_len = 0;
static int tx_data_curr_index = 0;

MODULE_AUTHOR("Ander GALISTEO/Diego JUARA");
MODULE_LICENSE("Dual BSD/GPL");

// April 04

enum  state {SENSING, RX, TX, ILLUM, CHM, NONE} ; // Short sensing is implemented in tx state
enum  state phy_state;

/////////////////// PRU variables ///////////////////////////////////

#define PRU_ADDR 0x4A300000
#define PRU0 0x00000000
#define PRU1 0x00002000
#define PRU_SHARED 0x00010000

unsigned int *tx_pru;
unsigned int *rx_pru;

struct net_device *vlc_devs;

struct vlc_packet {
	struct vlc_packet *next;
	struct net_device *dev;
	int	datalen;
	u8 data[2000+10];
};

struct vlc_packet *tx_pkt;
struct vlc_packet *rx_pkt_check_dup;
struct vlc_packet *rx_pkt;

int pool_size = 10;
module_param(pool_size, int, 0);

struct vlc_priv {
	struct net_device_stats stats;
	int status;
	struct vlc_packet *ppool;
	int rx_int_enabled;
	struct vlc_packet *tx_queue; // List of tx packets
	int tx_packetlen;
	u8 *tx_packetdata;
	struct sk_buff *skb;
	spinlock_t lock;
    struct net_device *dev;
};

static struct vlchdr *vlc_hdr(const struct sk_buff *skb)
{
    return (struct vlchdr *) skb_mac_header(skb);
}

int vlc_header(struct sk_buff *skb, struct net_device *dev, unsigned short type,
                const void *daddr, const void *saddr, unsigned len)
{
	struct vlchdr *vlc = (struct vlchdr *)skb_push(skb, VLC_HLEN);

	vlc->h_proto = htons(type);
	memcpy(vlc->h_source, saddr ? saddr : dev->dev_addr, dev->addr_len);
	memcpy(vlc->h_dest,   daddr ? daddr : dev->dev_addr, dev->addr_len);
	vlc->h_dest[MAC_ADDR_LEN-1] ^= 0x01;   /* dest is us xor 1 */
	return (dev->hard_header_len);
}

static const struct header_ops vlc_header_ops= {
    .create  = vlc_header
	//.rebuild = vlc_rebuild_header
};

// Return statistics to the caller
struct net_device_stats *vlc_stats(struct net_device *dev)
{
	struct vlc_priv *priv = netdev_priv(dev);
	return &priv->stats;
}

// Configuration changes (passed on by ifconfig)
int vlc_config(struct net_device *dev, struct ifmap *map)
{
	if (dev->flags & IFF_UP) // can't act on a running interface 
		return -EBUSY;

	// Don't allow changing the I/O address 
	if (map->base_addr != dev->base_addr) {
		printk(KERN_WARNING "snull: Can't change I/O address\n");
		return -EOPNOTSUPP;
	}

	// Allow changing the IRQ 
	if (map->irq != dev->irq) {
		dev->irq = map->irq; // request_irq() is delayed to open-time 
	}

	// ignore other fields 
	return 0;
}

// Ioctl commands
int vlc_ioctl(struct net_device *dev, struct ifreq *rq, int cmd)
{
	//printk("ioctl\n");
	return 0;
}


//Buffer/pool management.
struct vlc_packet *vlc_get_tx_buffer(struct net_device *dev)
{
	
	struct vlc_priv *priv = netdev_priv(dev);
	//unsigned long flags;
	struct vlc_packet *pkt;
    if (flag_lock)
        spin_lock_bh(&priv->lock);
	pkt = priv->ppool;
	priv->ppool = pkt->next;
	if (priv->ppool == NULL) {
		printk(KERN_INFO "The MAC layer queue is full!\n");
		netif_stop_queue(dev);
	}
    if (flag_lock)
        spin_unlock_bh(&priv->lock);
    
	return pkt;
}

void vlc_release_buffer(struct vlc_packet *pkt)
{
	//unsigned long flags;
	struct vlc_priv *priv = netdev_priv(pkt->dev);

	if (flag_lock)
        spin_lock_bh(&priv->lock);
	pkt->next = priv->ppool;
	priv->ppool = pkt;
	if (flag_lock)
        spin_unlock_bh(&priv->lock);
	if (netif_queue_stopped(pkt->dev) && pkt->next == NULL && flag_exit == 0)
		netif_wake_queue(pkt->dev);
}
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

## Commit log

2018-12-03 Bug fixed - Overwritten packets at transmission
    [openvlc.c]
2018-12-18 Fixed MTU length bug
    [openvlc.c]
2020-07-06 Move Files
    [OpenVLC1.3.1_BOM.xlsx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]
2020-07-06 Design files
    [BOM.xlsx, PCB_Design.PcbDoc, Schematics.SchDoc]
2021-03-03 Updated copper pour isolation at edges
    [PCB_Design.PcbDoc]
2021-03-06 move to folder replace with isolation of copper pour from edges
    [OpenVLC_1.3.1.DRL, OpenVLC_1.3.1.GBL, OpenVLC_1.3.1.GBO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]
2021-03-06 add copper pour isolation at edges in pcb design
    [PCB_Design.DRL, PCB_Design.GBL, PCB_Design.GBO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]
2022-06-16 Create SchematicsOpenVLC1_4.pdf
    OpenVLC 1.4 Schematics PDF added
2022-12-02 Pick and Place file added
    Added Pick and Place File for OpenVLC 1.3
    [Pick Place for PCB_Design.csv]
2022-12-02 Pick and Place file updated
    [Pick Place for PCB_Design.csv]
2022-12-07 Create Driver
2023-06-16 Create README.md
    Gerber files have been updated
2023-07-07 OpenVLC 1.4 beta - HW files updated
    Files for PCB fabrication of OpenVLC 1.4 beta uploaded. These include:
    - Gerber files
    - Drill file
    - BOM
    Extracted after migrating project from Eagle to Altium
    [BOM.xlsx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]
2023-07-07 Revert "OpenVLC 1.4 beta - HW files updated"
    This reverts commit 7af8bc83cf59f3558ae8a1d1a4102dc6b0b5d1f4.
    [BOM.xlsx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]
2024-10-31 First release of OpenVLC 1.3.2
    OpenVLC 1.3.2:
    - Power switch operating: no current leakage
    - Pin headers moved on the bottom layer, to avoid confusions during fabrication
    [BOM.xlsx, Bill of Materials-OpenVLC_1_3_2.xlsx, OpenVLC_1_3_2.PcbDoc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]
2024-11-28 Fabrication files updated
    Fabrication files updated to produce Gerber, NC Drill and PnP
    Publication to be used as reference updated
    [OpenVLC_1_3_2.GBL, OpenVLC_1_3_2.GBO, OpenVLC_1_3_2.GBP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]
2025-02-20 OpenVLC 1.3.2 removed
    [Bill of Materials-OpenVLC_1_3_2.xlsx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]
